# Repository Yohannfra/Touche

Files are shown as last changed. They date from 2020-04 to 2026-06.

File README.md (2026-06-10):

# Touché



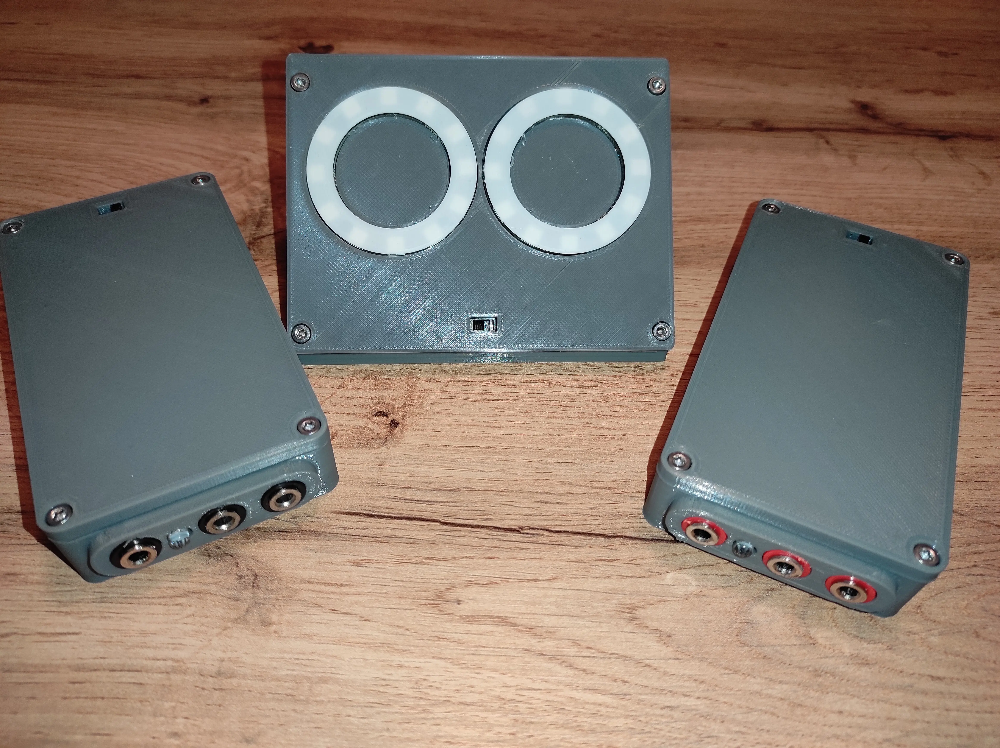
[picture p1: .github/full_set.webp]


## Overview

Touché is a wireless scoring system for fencing based on **Arduino** and **nrf24l01**.

The goal is to make an **affordable**, **open source** and **open hardware** system.

⚠️  The capacitive touch feature (used to detect whether a hit landed on a conductive surface like the guard or a metallic piste, replacing the ground wires of a traditional setup) is currently very buggy and not usable, which makes the system hard to use with **foil**.

⚠️  Foil and  sabre support is in the roadmap but in a latter version that will certainly be on a different mcu (ESP32 or STM32).

#### The system is divided into 3 parts: one base station and two fencer boxes.

*During the early days of this project I called the base station the **server**
and the fencer boxes the **clients**, I will use this naming in this document
and across the project.*

## Getting started

To make a system you'll have to go through these steps:
1. Order the PCB and all the components
2. 3D print the boxes
3. Program the Arduino
4. Solder the PCB and assemble everything
5. Enjoy!

I wrote a step-by-step tutorial that you can find in [Assembly_Guide](./Assembly_Guide).

If you have a question about anything (please read the tutorial first) you can open a Github issue and I will try my best to answer you.

## About the directory structure

This repository contains all the **sources**, **3D files**, and **PCB files** needed to make this system.

```
.
├── Archive           # some old versions of the project
├── Documents         # pcb sources, and STL files
├── Code              # source code
├── Assembly_Guide/   # step by step tutorial to DIY
```
Each directory has its own README.md to explain this with more details.

## Roadmap

See Github issues.

## Contribute

If you have any improvement idea, find a bug or encounter a problem you can open a Github issue.

## License

All the code, CAD files, PCB files, and everything within this repository is licensed under the terms of the [GNU General Public License V3.0](./LICENSE).

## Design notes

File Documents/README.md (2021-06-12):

# Documents

This directory contains all CAD files, 3D files (STL), and PCB files.

````
.
├── CAD       # CAD and STL files for 3D printing
└── PCB       # PCB sources and gerber files
```

Each directory has its own README.md to explain this with more details.

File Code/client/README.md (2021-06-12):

# Client source code

### Build

You must have the pio command available.

```bash
make           # debug version
make_release   # release version
```

### Flash

```bash
make flash           # debug version
make flash_release   # release version
```

### Change the default player

If it's the first time you program and Arduino with this code you must set which 'Player' it will be, it can be **PLAYER_1** or **PLAYER_2**
Once it's done once for an Arduino you should not need to change that anymore.

Change it in **./include/config.h** line 28

```cpp
#define PLAYER_ROLE PLAYER_1  // change value to PLAYER_1 or PLAYER_2
```

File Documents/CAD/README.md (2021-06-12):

# CAD

This directory contains the 3D STL files for the 2 boxes.

## Print settings

I printed all parts with **0.2 layer height** and **20% infill**.

I printed them all on my ender 3 pro so I don't think any of them can be considered as a difficult print.

You'll need supports for the **client's base** and the **server's base**.

You can print in any color but should print the server light diffuser in white for better results.

You can print in any material.

## Print time

This is just to give you an idea of the print time I had on my **ender 3 pro** at **50 mm/s** (and most of Cura's defaults settings) for PLA

| Part | Time  |
| --- | ----- |
| Client base | ~6h |
| Client lid  | ~4h |
| Server base | ~7h |
| Server lid  | ~4h |
| Light diffuser| 5 min |

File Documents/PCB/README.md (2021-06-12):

# PCB

This directory contains the PCB files and the Gerbers for the 2 boxes.

## Order the PCBs

Check the chapter about the PCB ordering in the [Assembly guide](../../Assembly_Guide/README.md)

## Quick note

I designed these PCBs with Eagle.

The Arduino nano and NRF24L01 parts come from here: https://www.diymodules.org/

I learned PCB with this project so they may not be perfect.

Please open an issue if you spot any design error.

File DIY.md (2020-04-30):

# A tutorial to help you create your wireless fencing system

## Components and supplies

- [3 : esp32 devboards](https://www.amazon.fr/AZDelivery-NodeMCU-d%C3%A9veloppement-d%C3%A9nergie-successeur/dp/B074RGW2VQ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)
- [3 : Neopixel ring](https://www.amazon.fr/dp/B07TZK9DNT/ref=twister_B0822WQBQX?_encoding=UTF8&psc=1)
- [1 : 12V buzzer](https://www.amazon.fr/LZQ-3022-Discontinu-alarme-Avertisseur-Sonore/dp/B010V4UVHG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)
- [6 : banana plugs](https://www.amazon.co.uk/KEESIN-Binding-Amplifier-Terminal-Connector-Type-D/dp/B077T2FC7K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)
- [3 : micro USB Tp4056 charger circuits](https://www.amazon.fr/Tp4056-Chargeur-Batterie-Lithium-Charger/dp/B07NVBLMVQ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)
- [3 : 3.7V batteries](https://www.amazon.fr/dp/B07KKB874V?ref=ppx_pop_mob_ap_share)
- [3 : power switches](https://www.amazon.fr/TOOGOO-broches-Positions-commutateur-glissiere/dp/B00X3KCA0M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)

#### Total cost : ~ 100€

## Building tools

- soldering iron
- 3d printer (i used an Ender 3, so event a cheap one should work)
- screwdriver
- a few screw
- some electric wire
- a hot glue pistol

## 3d printing

You can find all the files to print [here](thingverselink).

You need to print
- 2 : client_base.stl
- 2 : client_cover.stl
- 1 : server_base.stl
- 1 : server_cover.stl

The two bases need printing support.\
On my ender 3 without the adhesion it fails so i'd reccomend you to print all parts with adhesion.

## Flashing the boards

**An unix based system is needed for this part (Linux/Mac)**

- Install the [Arduino IDE](https://www.arduino.cc/en/Main/Software)
- Install [PlatformIO](https://platformio.org/)
- Clone and go to the repository
    ```
    $ git clone https://github.com/Yohannfra/WSFF && cd WSFF
    ```
- Sort yours esp32, 2 will be the clients and one will be the server
- Change directory
    ```
    $ cd tools/get_esp32_mac_address
    ```
- For each esp32 :
    - Plug the board to the computer and type
        ```
        make && make flash
        ```
    - Open screen to view the value of the mac address
        ```
        screen /dev/ttyUSB0 115200
        ```
    - Edit the file **constants.cpp** and replace the mac addresses with yours
        ```
            $ nano ../../shared/constants.cpp
        ```
    - Unplug the board

- Now go to the client directory
    ```
    $ cd ../../client/
    ```
- For your two client boards
    - Plug the board to the computer and type
        ```
        $ make && make flash
        ```
    - Unplug the board
- Now the server board
    ```
        cd ../server/
    ```
    - Plug the board to the computer and type
        ```
        $ make && make flash
        ```
    - Unplug the board

- Done !

## Soldering and assembling

**You need all the 3d printed parts now**

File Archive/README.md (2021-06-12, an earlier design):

# Archive

This directory contains the code of some early prototypes I did. I don't know if they work or even compile.
I keep this directory just to keep trace of these old prototypes.

**esp32_arduino_v1** and **esp32_espidf_v2** were made to run on Espressif ESP32 chip and used ESP-NOW.
Around the end of the v2, I realized that the ESP32 consumed way too much power and started over with Arduino nano.

The v1 coded with the Arduino framework and the v2 with the ESP-IDF framework.

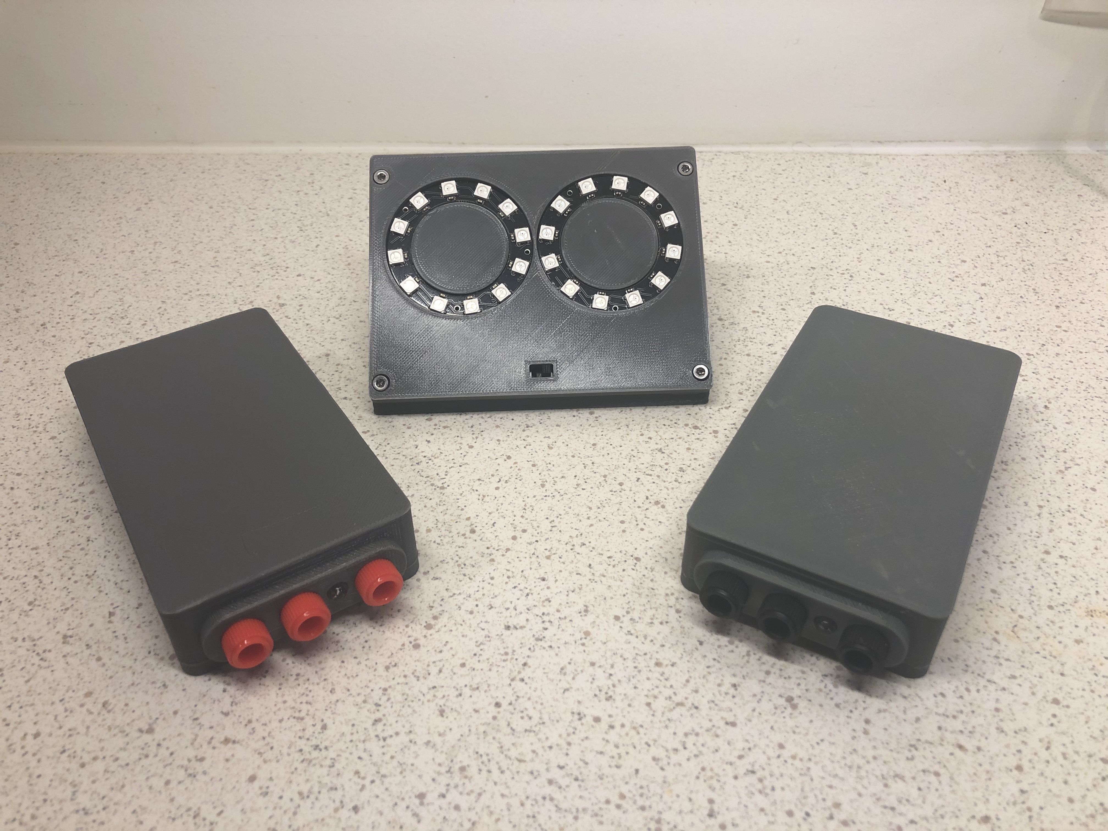
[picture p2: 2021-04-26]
.github/full_set.jpg

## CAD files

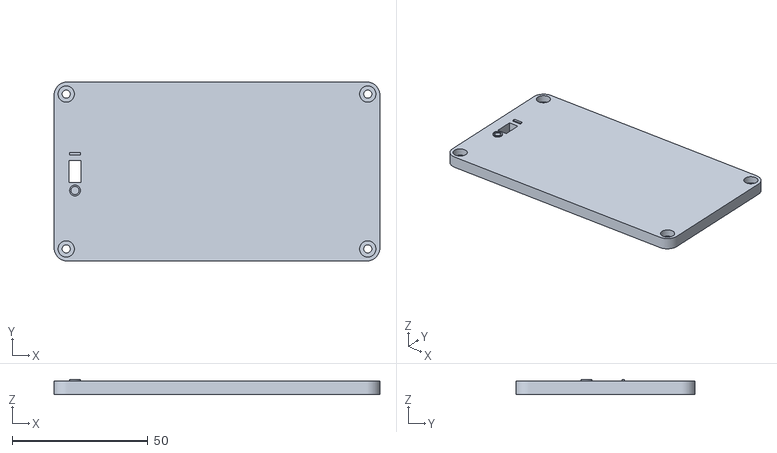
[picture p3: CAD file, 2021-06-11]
Documents/CAD/client/lid_client.stl
120.0 x 66.0 x 5.50

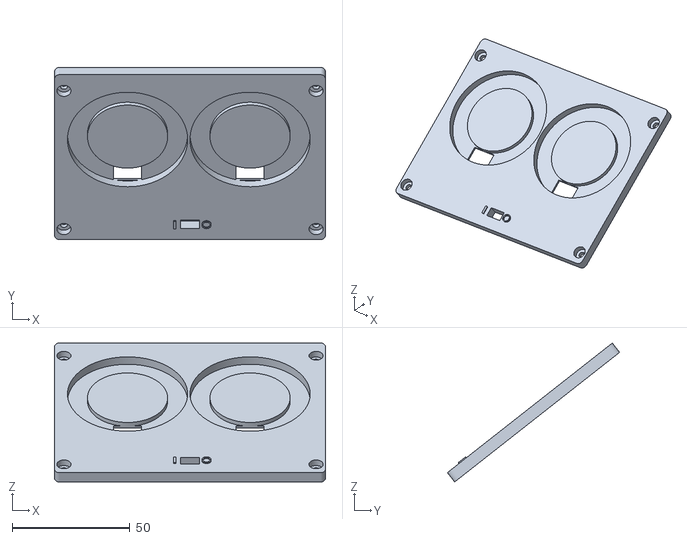
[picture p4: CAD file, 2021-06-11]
Documents/CAD/server/lid_server.stl
115.0 x 73.1 x 58.9

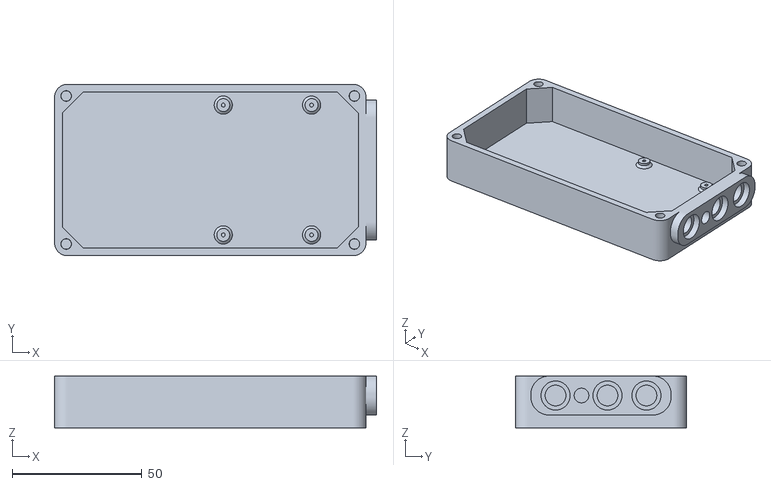
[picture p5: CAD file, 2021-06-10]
Documents/CAD/client/base_client.stl
124.0 x 66.0 x 20.0

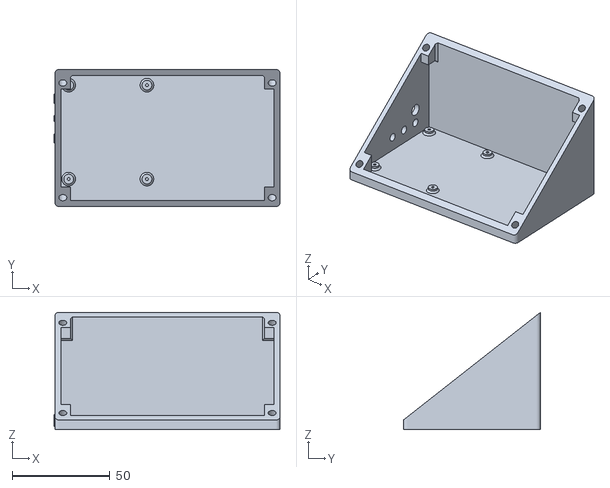
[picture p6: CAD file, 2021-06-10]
Documents/CAD/server/base_server.stl
115.5 x 70.0 x 60.0

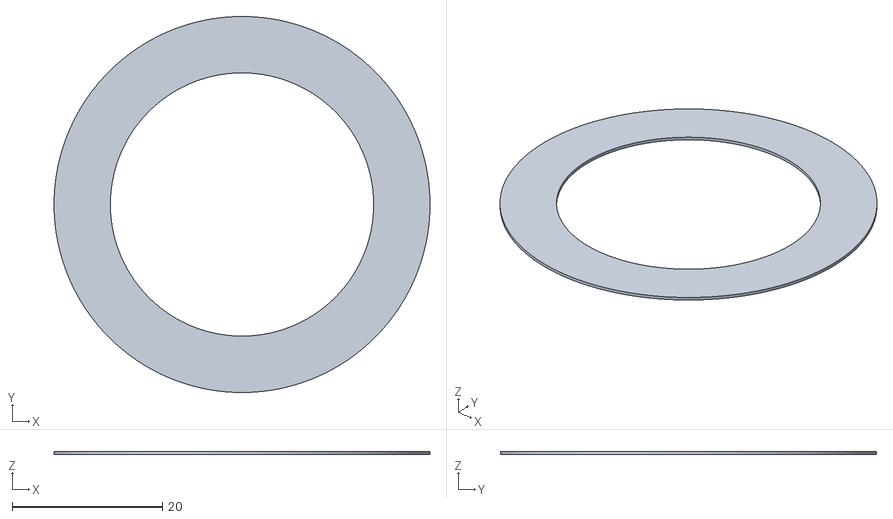
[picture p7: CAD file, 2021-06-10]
Documents/CAD/server/light_diffuser.stl
50.0 x 50.0 x 0.4

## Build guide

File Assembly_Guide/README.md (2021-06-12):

# Assembly guide

In this document, I will go through all the steps and explain everything needed to make a complete Touché system.

The total cost of the system sits somewhere around **50 euros** but since most parts are sold in batch you might pay a little more and end up with unused parts at the end of the assembly.

#### Table of Contents

1. [Parts, material and required tools](#p1)
2. [PCB](#p2)
3. [3D printing](#p3)
4. [Assembly](#p4)
5. [Testing / Usage](#p5)

<a name="p1"/>

### 1. Parts, material, and required tools

##### Here are all the parts required.

| Name | Quantity | URL  |
| --- | --- | ---- |
| Arduino nano | 3 | [Aliexpress](https://fr.aliexpress.com/item/32647196840.html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,searchweb201602_,searchweb201603_) [Arduino store](https://store.arduino.cc/arduino-nano) [Amazon](https://www.amazon.fr/Elegoo-Pi%C3%A8ces-ATmega328P-Contr%C3%B4leur-Arduino/dp/B0722YYBSS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) |
| NRF24L01 | 3 | [Aliexpress](https://fr.aliexpress.com/item/32517849393.html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,searchweb201602_,searchweb201603_) [Amazon](https://www.amazon.fr/AZDelivery-NRF24L01-Antenne-emetteur-recepteur-R%C3%A9cepteur/dp/B06XJN417D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) |
| AA battery case | 3 | [Aliexpress](https://fr.aliexpress.com/item/1005001707889794.html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,searchweb201602_,searchweb201603_) [Amazon](https://www.amazon.fr/HUAYAO-Batterie-Plastique-Stockage-Transparent/dp/B08VDHCD66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) |
| 10uF 16v electrolytic capacitor | 3 | [Aliexpress](https://fr.aliexpress.com/item/32812085542.html?spm=a2g0o.cart.0.0.3a7f3c00e96C79&mp=1) |
| RGB led (common cathode) | 2 | [Aliexpress](https://fr.aliexpress.com/item/32757977782.html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,searchweb201602_,searchweb201603_) |
| Neopixel ring (12 pixels, 50 mm diameter) | 2 | [Aliexpress](https://fr.aliexpress.com/item/32835427711.html?spm=a2g0s.9042311.0.0.27426c37UHtlV5) |
| Banana socket | 6 | [Aliexpress](https://fr.aliexpress.com/item/32871913429.html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,searchweb201602_,searchweb201603_) |
| Slide switch | 3 | [Aliexpress](https://fr.aliexpress.com/item/32807468914.html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,searchweb201602_,searchweb201603_) [Amazon](https://www.amazon.fr/Lezed-Interrupteur-Horizontal-commutateur-horizontal/dp/B07LBPDB6S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) |
| Threaded inserts (M3 x 5,7mm) | 12 | [Aliexpress](https://fr.aliexpress.com/item/4001258499799.html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,searchweb201602_,searchweb201603_) |
| 1MΩ resistor | 6 | Full ressistor Kit [Amazon](https://www.amazon.fr/ELEGOO-R%C3%A9sistance-Electroniques-Exp%C3%A9rimentalur-Exp%C3%A9rimental/dp/B071LHFQKD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) [Aliexpress](https://fr.aliexpress.com/item/1005001968824337.html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,searchweb201602_,searchweb201603_) |
| 10 KΩ resistor | 2 | Same ressistor Kit |
| 0 Ω resistor | 2 | Same ressistor Kit |
| 220 Ω resistor | 6 | Same ressistor Kit |
| Buzzer SFM-27 | 1 | [Aliexpress](https://fr.aliexpress.com/item/1005002095783515.html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,searchweb201602_,searchweb201603_) [Amazon](https://www.amazon.fr/YANSHON-Buzzer-dAlarme-Avertisseur-%C3%A9lectronique/dp/B07RY42FQ5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) |
| AA battery | 9 | [Amazon](https://www.amazon.fr/Duracell-Plus-Power-Piles-Alcalines/dp/B005EJFLJC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) or any local store |
| Bolt (M3 x 10) | 12 | [Aliexpress](https://fr.aliexpress.com/item/33012853233.html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,searchweb201602_,searchweb201603_) [Amazon](https://www.amazon.fr/100pcs-Boulon-Hexagonale-Cylindrique-inoxydable/dp/B073ZY19VS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) |
| Mini screws (M1.75 x 5) | 12 | [Aliexpress](https://fr.aliexpress.com/item/4000930559532.html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,searchweb201602_,searchweb201603_) [Amazon](https://www.amazon.fr/1000pcs-minuscules-crois%C3%A9e-dassortiment-autotaraudeurs/dp/B07WXHH6ZL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) |
| 5kΩ potentiometer | 1 | [Aliexpress](https://www.aliexpress.com/item/1005002056193990.html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,searchweb201602_,searchweb201603_) |
| Right angle push button switch (6 x 6 x 9 mm) | 3 | [Aliexpress](https://www.aliexpress.com/item/32901481925.html?spm=a2g0s.9042311.0.0.17af6c37yXC24E) |

##### Tools / consumables you'll need

- 3D printer (I printed all the parts on my Ender 3 so I think any decent printer could get the job done)
- Soldering iron and solder wire
- Hot glue gun and glue
- Screwdrivers
- Wire cutting pliers
- A few wires (I have [those](https://www.amazon.com/TUOFENG-Wire-Solid-different-colored-spools/dp/B07TX6BX47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))

<a name="p2"/>

### 2. PCB

Ordering the PCBs is quite simple and cheap. I will show how to do it with [JLCPCB](https://jlcpcb.com/) but it should be similar on [PCBWay](https://www.pcbway.com/) or any similar website.

1. Go to https://jlcpcb.com/

2. Leave all the defaults settings and click on 'Quote now'

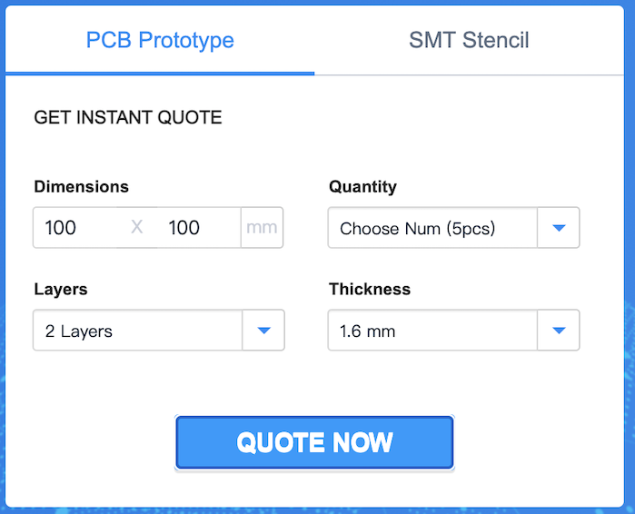
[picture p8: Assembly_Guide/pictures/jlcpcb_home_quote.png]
jlcpcb_home_quote


3. Import the client's gerber file (it the .zip in [this](https://github.com/Yohannfra/Touche/tree/master/Documents/PCB/client) directory)

jlcpcb_import_gerber

4. Save to cart and **repeat this process for the server's gerber file** ([here](https://github.com/Yohannfra/Touche/tree/master/Documents/PCB/server))

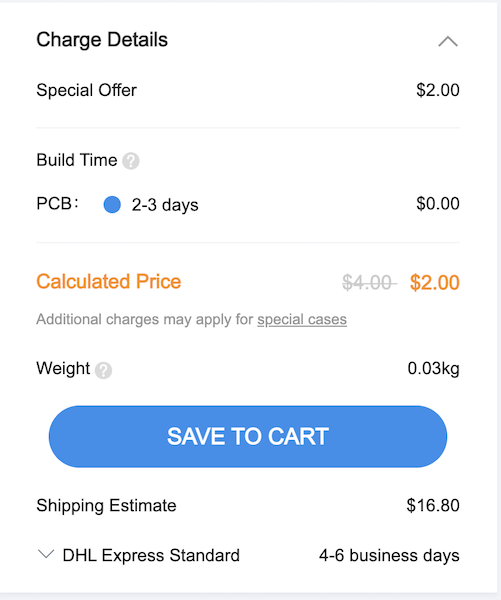
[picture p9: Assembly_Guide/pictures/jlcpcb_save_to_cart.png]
jlcpcb_save_to_cart


5. Pay and order.

<a name="p3"/>

### 3. 3D printing

8 printed parts are needed for the assembly :

| Name | Link | Quantity | Time needed | Supports |
| --- | --- | --- | --- | --- |
| Client's base | [url](https://github.com/Yohannfra/Touche/tree/master/Documents/CAD/client/base_client.stl) | 2 | ~4h | Yes |
| Client's lid | [url](https://github.com/Yohannfra/Touche/tree/master/Documents/CAD/client/lid_client.stl) | 2 | ~4h | No |
| Server's base | [url](https://github.com/Yohannfra/Touche/tree/master/Documents/CAD/server/base_server.stl) | 1 | ~6h | Yes |
| Server's lid | [url](https://github.com/Yohannfra/Touche/tree/master/Documents/CAD/server/lid_server.stl) | 1 | ~4h | No |
| Light diffuser | [url](https://github.com/Yohannfra/Touche/tree/master/Documents/CAD/server/light_diffuser.stl) | 2 | ~10 min | No |

I recommend printing all of them with **20% infill** and **0.2mm layer height** and face up.

<a name="p4"/>

### 4. Assembly

Before starting the assembly make sure you have everything, you should have all the parts shown in this picture:

all_parts

The assembly process is divided in 5 steps :
1. [client's pcb](./Step1.md)
2. [server's pcb](./Step2.md)
3. [programming](./Step3.md)
4. [client's assembly](./Step4.md)
5. [server's assembly](./Step5.md)

<a name="p5"/>

### 5. Testing / Usage

##### Turn on of the client, if the led is :
- Red -> Epee mode
- BLUE -> Foil mode
- GREEN -> Sabre mode (Not implemented yet)
- Something else / nothing -> Something is wrong, check the assembly guide again.

##### Same for the second client.

##### Now turn on the server, the led rings should blink in orange, if no check the assembly guide again.

### For epee

Plug your epee in, if you press the button the server will signal it.

By default if you touch the opponent guard it won't detect it, you must calibrate it.

To calibrate the client you need to maintain the button of your epee on his guard until the server LED blinks in led (~3 seconds). If it blinks in red, an error occurred and you must try again.\
This needs to be done each time something changes (new opponent, new weapon, new shoes, different piste ...).

Both opponents need to do this once and the system will be good to go.

One player will be signaled in green and the other one in red.

### For foil

Plug your foil in, if you press the button the server will signal it as an invalid hit.

By default all hits will be invalid, you must calibrate it.

To calibrate the client you need to maintain the button of your foil on electric jacket until the server LED blinks in led (~3 seconds). If it blinks in red, an error occurred and you must try again.\
This needs to be done each time something changes (new opponent, new weapon, new shoes, different piste ...).

Both opponents need to do this once and the system will be good to go.

One player will be signaled in green and the other one in red.

### About the buttons on the side of the server

There are 3 buttons and a potentiometer on the side of the server box.

The potentiometer controls the volume of the buzzer.

Starting from the left:
- First buttons are here to switch sides, eg. Player 1 hits are signaled on the left but he is on the right side of the server, press this button and he will be signaled on the right.
- Second button toggles piste mode, it will detect the piste and won't signal if a hit occurs on it (still not tested because I don't have an electric piste at home but it should work)
- Third button changes weapon, press it and then hit with each player weapon to 'transfer the information' so the next hit will be in the new weapon mode.

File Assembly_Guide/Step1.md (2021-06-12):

# Step 1 : Client's PCB

This first step is for soldering everything onto the client's pcb. Since there are 2 clients you'll need to **do this step twice**.

1. Take the client's pcb



2. Take the Arduino Nano (and solder the leads if needed)

before the leads

after the leads

3. Solder the Arduino Nano on the pcb

arduino soldered

4. Take the NRF24L01 and solder it on the pcb

nrf soldered

5. Take the 10uF capacitor and solder it (be careful, it's a polarized capacitor and therefore the positive side must match the little + on the pcb)

take the cap

solder the cap

6. take the 3 220 ohms resistors and solder them

3 220 ohms

3 220 soldered

7. Take the 10k ohms resistor and solder it

10k resistor

10k soldered

8. Take the 2 1M ohms resistors and solder them

2 1M resistors

2 1M soldered

9. Take the RGB led and solder it. Be careful, of the side and place it like on the picture before soldering. Once soldered, bend the leads like on the pictures.

rgb led

rgb led soldered

10. Flip the pcb and cut all the leads

    cut the leads

leads cut

11. Take one of the lead and solder it across the empty resistor slot.

take a lead

solder the lead

And ... Done ! Now repeat all these steps a second time for the second pcb. At the end you should have two pcbs like that:

two clients's pcbs

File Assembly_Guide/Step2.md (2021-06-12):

# Step 2 : Server's PCB

This second step is for soldering everything onto the server's pcb.

1. Take the server's pcb

server pcb

2. Take the 3 buttons and solder them

3 buttons

buttons soldered

3. Take the potentiometer and solder it

potentiometer

potentiometer soldered

4. Take the NRF24L01 and solder it

take nrf24

solder nrf24

5. Take the Arduino Nano (solder the leads if needed) and solder it on the pcb

before the leads

after the leads

arduino nano and pcb

arduino nano soldered

5. Take the 10uF capacitor and solder it (be careful, it's a polarized capacitor and therefore the positive side must match the little + on the pcb)

take cap

solder cap

And you're done with the pcbs ! Now you should have all three pcbs :

all pcbs

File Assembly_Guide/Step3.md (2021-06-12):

# Step 3 : Programming

In this step I'll show how to program everything.

In this step I'll do everything with the command line (I'm on Mac) and those commands also work on linux. If you're on Windows you could use [WSL](https://docs.microsoft.com/fr-fr/windows/wsl/install-win10) or try to do everything with vscode.

Clone the git repository

```
$ git clone https://github.com/Yohannfra/Touche
```

Install platformio core : https://docs.platformio.org/en/latest//core/installation.html

Once it's done you should have the command pio

```
$ pio --version
PlatformIO Core, version 5.1.1
```

### Select the default weapon

in **Code/shared/touche.h** line number **78**

by default it's
```c
#define DEFAULT_WEAPON_MODE EPEE
```

For now only **EPEE** and **FOIL** are available.

### Server

Go to the server's directory

```
$ cd Code/server/
```

Build the code

```
$ make release
```

Plug the server's pcb

plug the server's pcb

and run

```
$ make flash_release
```

You can now unplug the server's pcb.

### Client

Now go to the client's directory

```
$ cd ../client
```

Build the code

```
$ make release
```

Plug the first pcb (**only the first**)

flash client

and run

```
$ make flash_release
```

you can unplug the pcb. Normally when the **make flash_release** ended the led blinked in red.

Now you'll have to edit a file, open **include/config.h"** in the client's directory and change this line (line 28)

```c
#define PLAYER_ROLE PLAYER_1  // change value to PLAYER_1 or PLAYER_2
```

to

```c
#define PLAYER_ROLE PLAYER_2  // change value to PLAYER_1 or PLAYER_2
```

Now save the file and close it.

Now build the code again

```
$ make release
```

Plug the second client's pcb and run

```
$ make flash_release
```

And now you should be done with the programming part. You can skip the next part if you want to make only one system.

## If you want to make multiple systems

Between each system you should change the nrf24l01 pipes addresses, it's in the file **Touche/Code/shared/radioPipes.h"**

The default pipe address is

```cpp
static const uint64_t PIPES_ADDRESSES[2] = {
    0xB3B4B5B601LL,  // PLAYER 1
    0xB3B4B5B602LL   // PLAYER 2
};
```

You can change that to anything as long as :

- The length is the same
- The two addresses are different
- You keep the **0x** at the beginning and the **LL** at the end

A few valid examples:

```cpp
static const uint64_t PIPES_ADDRESSES[2] = {
    0xB5C4B5B601LL,  // PLAYER 1
    0xB5C4B5B602LL   // PLAYER 2
};

static const uint64_t PIPES_ADDRESSES[2] = {
    0xB1B4B5B601LL,  // PLAYER 1
    0xB1B4B5B602LL   // PLAYER 2
};

static const uint64_t PIPES_ADDRESSES[2] = {
    0xA9B4B5B601LL,  // PLAYER 1
    0xA9B4B5B602LL   // PLAYER 2
};

// ...
```

Refer to this thread if you want to know more about it: https://arduino.stackexchange.com/questions/2946/nrf24l01-pipe-question

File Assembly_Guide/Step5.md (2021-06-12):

# Step 5 : Server's assembly

This step is for assembling the server's pcb to the printed parts and finishing the server's box.

1. Take the server's base and 4 threaded inserts, place them in the holes and push them inside with a soldering iron  (watch [this video](https://www.youtube.com/watch?v=KqSmCHr4fdA) if you need help)





2. Take the server's lid, a slide switch, 2 screws and screw the switch.





3. Now take the 2 led rings and glue them in the slots with the glue gun, make sure the pins are accessible in the hole on the back of the lid.









4. Take the light diffusers and glue them on top of the rings





5. Take the server's pcb and the buzzer and solder the buzzer





6. Take 5 wires, 1x9cm and 4x5cm



take the server's lid



And solder them like this, the **DO** of the first ring must be connected to the **DI** of the second one



7. Take 3x8cm wires and 2 heat shrink tubes



Place the heat shrink tubes like this



Solder the matching wires



Solder the new wires at the connection and place the heat shrink tubes around the exposed part and heat them



8. Take the pcb and the lid



Solder the wires to the pcb



9. Take a 9cm wire and solder it to the middle pin of the slide switch and to the **VCC** of the pcb





10. Take the base, the lid and 2 screws and screw the pcb





11. Take the AA battery holder and cut it's wires like this



Take the glue gun and glue the AA battery holder and the buzzer









12. Solder the red wire of the AA battery holder to the left side pin of the slide switch



13. Take the 3 AA batteries and place them in the holder





14. Take the M3 screws and close the lid





And you're done ! Now you should have all the three parts



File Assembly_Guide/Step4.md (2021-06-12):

# Step 4 : Client's assembly

This step is for assembling the client's pcb to the printed parts and finishing the clients boxes.

1. Take the client's base and 4 threaded inserts, place them in the holes and push them inside with a soldering iron (watch [this video](https://www.youtube.com/watch?v=KqSmCHr4fdA) if you need help) 

client and inserts

inserts placed

inserts in

2. Take the client's lid, the slide switch and 2 screws and screw the button

lid and switch

slide switch placed

3. Take the client's base and 3 banana sockets (like shown on the picture). Screw the sockets.

all banana sockets

banana sockets placed

4. Take the **client's base**, **three 3cm  long wires** and the client's pcb 





Solder the wires on the pcb.



Now take 3 screws and screw the pcb.





Solder the wires onto the banana sockets



5. Take the AA battery holder



Cut the wires, the black one around 5cm and the red one around 9cm



6. Take the client's base, the AA battery holder and a hot glue gun, and glue the battery holder like shown in the picture







7. Solder the black wire to the GND pin on the pcb



Slide the wire on between the AA holder and the side of the case



7. Take a 12cm wire, the client's lid and solder the wire to the right pin of the switch







8. Now take the base and the lid



Solder the red wire to the middle pin of the switch and the white wire to the VCC pin of the pcb



9. Take 3 AA batteries and place them inside the holder





10. Close the lid and screw it with 4 M3 screws







And you're done ! Now do it again for the second client.

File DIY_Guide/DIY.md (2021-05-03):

# DIY guide

In this document I will go trough all the steps and explain everything needed to make a complete Touché system.

The total cost of the system sits somewhere around **50 euros** but since most parts are sold in batch you might pay a little more and end up with unused parts at the end of the assembly.

#### Table of Contents

1. [Parts, material and required tools](#p1)
2. [PCB](#p2)
3. [3D printing](#p3)
4. [Programming](#p4)
5. [Assembly](#p5)
6. [Testing](#p6)

<a name="p1"/>

### 1. Parts, material and required tools

##### Here are all the parts required.

| Name | Quantity | URL  |
| --- | --- | ---- |
| Arduino nano | 3 | [Aliexpress](https://fr.aliexpress.com/item/32647196840.html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,searchweb201602_,searchweb201603_) [Arduino store](https://store.arduino.cc/arduino-nano) [Amazon](https://www.amazon.fr/Elegoo-Pi%C3%A8ces-ATmega328P-Contr%C3%B4leur-Arduino/dp/B0722YYBSS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) |
| NRF24L01 | 3 | [Aliexpress](https://fr.aliexpress.com/item/32517849393.html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,searchweb201602_,searchweb201603_) [Amazon](https://www.amazon.fr/AZDelivery-NRF24L01-Antenne-emetteur-recepteur-R%C3%A9cepteur/dp/B06XJN417D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) |
| AA battery case | 3 | [Aliexpress](https://fr.aliexpress.com/item/1005001707889794.html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,searchweb201602_,searchweb201603_) [Amazon](https://www.amazon.fr/HUAYAO-Batterie-Plastique-Stockage-Transparent/dp/B08VDHCD66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) |
| 10uF 16v electrolytic capacitor | 3 | [Aliexpress](https://fr.aliexpress.com/item/32812085542.html?spm=a2g0o.cart.0.0.3a7f3c00e96C79&mp=1) |
| RGB led (common cathode) | 2 | [Aliexpress](https://fr.aliexpress.com/item/32757977782.html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,searchweb201602_,searchweb201603_) |
| Neopixel ring (12 pixels, 50 mm diameter) | 2 | [Aliexpress](https://fr.aliexpress.com/item/32835427711.html?spm=a2g0s.9042311.0.0.27426c37UHtlV5) |
| Banana socket | 6 | [Aliexpress](https://fr.aliexpress.com/item/32871913429.html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,searchweb201602_,searchweb201603_) |
| Slide switch | 3 | [Aliexpress](https://fr.aliexpress.com/item/32807468914.html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,searchweb201602_,searchweb201603_) [Amazon](https://www.amazon.fr/Lezed-Interrupteur-Horizontal-commutateur-horizontal/dp/B07LBPDB6S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) |
| Threaded inserts (M3 x 5,7mm) | 12 | [Aliexpress](https://fr.aliexpress.com/item/4001258499799.html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,searchweb201602_,searchweb201603_) |
| 1MΩ resistor | 6 | Full ressistor Kit [Amazon](https://www.amazon.fr/ELEGOO-R%C3%A9sistance-Electroniques-Exp%C3%A9rimentalur-Exp%C3%A9rimental/dp/B071LHFQKD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) [Aliexpress](https://fr.aliexpress.com/item/1005001968824337.html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,searchweb201602_,searchweb201603_) |
| 10 KΩ resistor | 2 | Same ressistor Kit |
| 0 Ω resistor | 2 | Same ressistor Kit |
| 220 Ω resistor | 6 | Same ressistor Kit |
| Buzzer SFM-27 | 1 | [Aliexpress](https://fr.aliexpress.com/item/1005002095783515.html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,searchweb201602_,searchweb201603_) [Amazon](https://www.amazon.fr/YANSHON-Buzzer-dAlarme-Avertisseur-%C3%A9lectronique/dp/B07RY42FQ5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) |
| AA battery | 9 | [Amazon](https://www.amazon.fr/Duracell-Plus-Power-Piles-Alcalines/dp/B005EJFLJC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) or any local store |
| Bolt (M3 x 10) | 12 | [Aliexpress](https://fr.aliexpress.com/item/33012853233.html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,searchweb201602_,searchweb201603_) [Amazon](https://www.amazon.fr/100pcs-Boulon-Hexagonale-Cylindrique-inoxydable/dp/B073ZY19VS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) |
| Mini screws (M1.75 x 5) | 16 | [Aliexpress](https://fr.aliexpress.com/item/4000930559532.html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,searchweb201602_,searchweb201603_) [Amazon](https://www.amazon.fr/1000pcs-minuscules-crois%C3%A9e-dassortiment-autotaraudeurs/dp/B07WXHH6ZL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) |

##### Tools you'll need

- 3D printer (I printed all the parts on my 150$ ender 3 so IMO any decent printer could do the job)

- Soldering iron

- Hot glue gun

- Screwdriver 

- Wire cutting pliers

##### Additional material

- Hot glue
- Solder wire
- A few wires (I have [those](amazon.com/TUOFENG-Wire-Solid-different-colored-spools/dp/B07TX6BX47/ref=sr_1_5?dchild=1&keywords=wires&qid=1620082408&sr=8-5))

<a name="p2"/>

### 2. PCB

<a name="p3"/>

### 3. 3D printing

<a name="p4"/>

### 4. Programming

<a name="p5"/>

### 5. Assembly

<a name="p6"/>

### 6. Testing

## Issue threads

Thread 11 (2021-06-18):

Could Touche be adapted for Boffer Combat?

DrAlta, 2021-06-18:
Hello. I was to use an automated scoring system for my Boffer Combat.

The main things I can think of is that Boffer Combat has many opponents at one and multi hit locations.

Would I just have change the software to track more that 2 combatants then to change the hardware to add multiple lamè connectors?

Edit: correct epee to lamè

Yohannfra, 2021-06-18:
Hello.
I don't know anything about Boffer Combat, is there already an electric system (wireless or no) that works ?

A fencing epee/foil has a button and an electric wire within the blade conducting the button state, I don't think there is something similar for Boffer Combat weapons.

DrAlta, 2021-06-18:
I just learned the the Epee is a type of weapon the armor is called lamè.

I failed the math part of first semester of Electronic Repair Technician program I was in, now I do software.
I don't know of any automatic scoring systems than Fencing's and Unified Weapons Master which w never released and has been quite since 2017.

How do you detect if a hit is valid?

I guess it would be more like sabre which you don't support yet....

Yohannfra, 2021-06-19:
I detect if a hit occurred using the button at the tip of the epee/foil.

Yes it's more like sabre and seems to be more complicated since weapons are in foam.

I think this is out the scope of Touché for now and prefer to stay focused on traditional fencing with foil, epee and sabre.

You can still fork and try to find a way to make it work but I don't think it will be trivial.

Closed 2021-07-02.

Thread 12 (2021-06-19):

Interested in this project

young-oct, 2021-06-19:
Hi there,

Very cool project and I'm interested in knowing more. I'm wondering if you have some research material to tackle this project. Feel free to contact me by dropping me an email young.wang93@gmail.com

Yohannfra, 2021-06-19:
Hello,
Glad to hear you're interested in this project !

I didn't write any documentation while researching but a complete diagram + some doc about how it works is planned. What else would you need to tackle it ?

young-oct, 2021-06-29:
@Yohannfra hello. Sorry about the late response. I'm a fencer myself and have been always interested in doing a project like this. And I think it would be fun to learn some PCB design and programming while doing it. It's great that complete diagram + some doc is planned/

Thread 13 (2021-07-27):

Wiring question...

bhfoilist, 2021-07-27:
I've built the boxes and checked that they are working by enabling debug mode.  I'm able to see messages between the client and server, and it seems like epee touches work.  Unfortunately, they also trigger on the bell guard.  Is the capacitive sensor supposed to detect the bell guard and disable the signal?

Also, I'm not sure foil is working correctly, and it seems like the pins might be mixed up.  Normally, the middle pin on the foil body cord carries the voltage up the wire in the weapon; however, the voltage seems to be on the alligator clip instead.  Can you explain how the pins are intended to work with this system?  I only get foil touches if I connect the weapon (not the tip) to the alligator clip--not if I press the tip.

Thanks!

Yohannfra, 2021-07-29:
Hello, yes the foil mode is broken and not usable yet. I update the README.

The problem you have seems not related to the capacitive sensor, can you provide more infos about your bug ? (any logs ?)

paxon1, 2022-09-23:
Hello,
  I am troubleshoot a first time build, which I assume is a soldering problem. How do I enable debug more to verify wireless connectivity between client/server.

Yohannfra, 2022-09-26:
Hi @paxon1, as it is written in the documentation to enable the debug mode and view the mode just build with ```make``` then flash with ```make flash```

link: https://github.com/Yohannfra/Touche/tree/master/Code/client

luczynski, 2023-08-03:
hi- after chenging  on player_2  and uploading in VCS -VISUAL CODE  - EWRYSING LITING  ONLY- RED COLER - one RED side  LITING ?  for two  player ? !   - HOW TEST ON GARDA  TOUCH -?
   wieslaw.luczynski@gmail.com      3.08.2023

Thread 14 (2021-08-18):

Timing question

ncaccamo, 2021-08-18:
Looking at touche.h, line 65 (as of Jun 13th commit), the double touch time is set to 300ms. Above in the comments, it is explained that there is ~260ms of processing time when both tips are pressed. For clarification, does this mean that the system cannot meet the rules timing requirements to distinguish between a single touch or double touch due to processing/communication delays?

I am also wondering what are good methods to measure these timings across the whole system given the various factors?

Yohannfra, 2021-08-30:
Yes, the rule says that a double hit must be made within 50ms but the minimum timing I got when pressing the two buttons at the exact same time was 260ms, so by setting 300ms I give a little more tolerance to this timing and it works better.
From what I tested the difference is almost not noticeable.

I don't have any 'good' method to test the timings, I just press the two buttons at the exact same time and read the millis() difference of the two when the server receive it

Riposte63, 2021-09-19:
Hi, There is also the question of how long the tip is depressed before a hit will register (I think 17ms for foil?) - is this in the code somewhere? I couldn't find it and would like to be able to adjust these timings.

Yohannfra, 2021-09-23:
You can look at client/lib/Weapon/src/Weapon.cpp and client/src/main.cpp

If the tip is pressed the hit will register instantly. where did you find 2ms ?
Actually It should wait a few ms but it was causing some latency so I removed it for now until I find a solution.

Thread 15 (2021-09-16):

Epee Mode

brunorosaa, 2021-09-16:
Hello, I recently did a project for my graduation in Eletrotecnic Engineering but my capacitive sensor sometimes works, sometimes not. I'm interested in your capacitive sensor, does it always work without any problem?
Thanks

Yohannfra, 2021-09-23:
Hello, no not at all for the moment. It kind of works for epee but is not reliable at all.
I'm now experimenting with other capacitive sensors solution (STM32L152 internal sensor) but it's not ready yet.

brunorosaa, 2021-09-23:
Hélio, thanks for the reply!
I try to use the internal capacitive sensor of an esp32 but it doesn’t have the necessary resolution. I’m just sharing my experience with that sensor’s. Keep the good work!
Best regards
Bruno Rosa

No dia 23/09/2021, às 08:57, Yohann ***@***.***> escreveu:

Hello, no not at all for the moment. It kind of works for epee but is not reliable at all.
I'm now experimenting with other capacitive sensors solution (STM32L152 internal sensor) but it's not ready yet.

—
You are receiving this because you authored the thread.
Reply to this email directly, view it on GitHub<https://github.com/Yohannfra/Touche/issues/15#issuecomment-925584617>, or unsubscribe<https://github.com/notifications/unsubscribe-auth/ANZBXAFH6QDKREZIQSBYC63UDLMV7ANCNFSM5EDUS7XQ>.
Triage notifications on the go with GitHub Mobile for iOS<https://apps.apple.com/app/apple-store/id1477376905?ct=notification-email&mt=8&pt=524675> or Android<https://play.google.com/store/apps/details?id=com.github.android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>.

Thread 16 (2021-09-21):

PWM detection instead of capacitance detection for future iterations

s0210310, 2021-09-21:
Hi,
Big fan of the project! I was also thinking of developing a system, but this is great. While researching the issue of detecting guard hits (talking epee specifically), the question has been posed multiple times, without a good answer besides capacitive sensing, which has its obvious drawbacks.

According to this thread, https://forum.arduino.cc/t/wireless-fencing-scoring-system-detecting-a-pwm-signal-without-common-ground/686963 the patent for true wireless systems uses PWM detection to discriminate against grounded hits. Now, the issue is that without a common ground, floating detector pins will give a lot of false negatives.

But, doing further investigation (reply nr 8 here https://www.avrfreaks.net/forum/communication-wout-common-ground) 100kHz and up signal could be detected reliably.
I believe with some care it's possible to use Arduino as a signal generator to drive 100kHz PWM signal to grounded surfaces and detect it with the depressed point. I'll try and experiment with this to confirm I can detect PWM without a common ground.

Your thoughts?

Yohannfra, 2021-09-23:
Hi,
As you can see at the end of the Arduino forum thread I talked with Luis320 in pm and from what I remember of our messages he could not get his pwm solution to work reliably enough for epee and for sabre it was too slow (from what he said).

If by experimenting you can find a way to make it work reliably it can be 100% better than capacitive sensing !

You said 'the patent for true wireless systems' does it means the pwm solution is patented and we can't use it at all ?

For you information last year I talked with @maxhaton and he tried to make it work using radio wave (see [here](https://www.reddit.com/r/Fencing/comments/g87ucg/successfully_detecting_a_fencing_hit_using_a/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)) so this could also be a solution.

Yohannfra, 2021-09-23:
Right now I'm sticking with capacitive sensing, I'm experimenting with the internal capacitive sensor of an STM32L152 but it would be interesting to compare all the solutions.

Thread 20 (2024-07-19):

Info about touch sensing and timing

wnew, 2024-07-19:
Hi @Yohannfra

Firstly what a great project. This  is something I have tried to implement myself over the years and I am excited to see that you have solved some of the problems I encountered. I would be keen to hear how you solve them.

On target sensing for foil? How did you manage this, was it with the capacitive sensor on the attacking fencer?

Then the timing between the 2 fencers, particularly lockout. How do you synchronise the 2 clients and then ensure that if an NRF packet is lost and needs to be re transmitted that it doesnt mess with the timing? Do you put a time stamp in the packet that is synced to the client clock?

Again, awesome project. I am keen to collaborate if you are interested to take this further.

Regards

W (Author of https://github.com/wnew/fencing_scoring_box)

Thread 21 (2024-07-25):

Collaboration

wnew, 2024-07-25:
Hi @Yohannfra,

I have been looking at this project and love what you have done. I am the author of the https://github.com/wnew/fencing_scoring_box.

I have been upgrading and creating a couple of PCB designs for my design and would like to collaborate. Would you be interested in having a chat sometime?

Regards

Wes

nova0205, 2024-08-09:
this colaboration gonna be awsome

wnew, 2024-08-12:
@nova0205 unfortunately it doesnt seem that @Yohannfra is supporting this project anymore.

I have some big updates coming for the project I linked above and have started working on a wireless system as well.

Regards

Yohannfra, 2024-08-12:
Hi @wnew,

Thank you for your interest and this collaboration proposition.

You are right, I didn't support this project for years and all I did since the initial release was some small fixes here and there across the project.

The main reason I stopped working on this project is that I was stuck. I couldn't find a solution for the 'common ground' feature. This is the most important feature for such a system but I overlooked it and it doesn't work and won't work with this current implementation with the arduino 'CapacitiveSensor' library, it's too imprecise and not reliable.

I'm mainly a software engineer and don't have enough knowledge in electrical engineering to find how to solve it.

I'd be really interested in a collaboration and willing to get back to this project if we can find how to solve this first.

Last year I also started a V2 based around a NRF52 dongle to improve the fabrication cost and complexity. I now have this V2 that is much much simpler and smaller but I can't release anything if the common ground is not solved first.

V1 client box compared to v2:
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

Let me know if you want to collaborate so we can discuss how it can be done.

Regards

Yohann

wnew, 2024-08-12:
Thank you very much for your reply @Yohannfra

You are right, there are 2 major hurdles to the wireless scoring apparatus. The main one being the lack of a common ground, which could be solved in a couple of ways, but most of these are really complex to implement with the required precision.  The second one is the synchronisation of the 2 "client" devices to within a millisecond. This is vital as wireless communications can be flaky and often require a resend of the packet, so we cant rely on time of arrival at the server side.

I see 3 possible solutions to the common ground problem. 1. Capacitive touch sensing, this takes time to detect and also requires calibration. 2. Time domain reflectometry, highly complex and costly to implement at the nano second scale. 3. Some type of RF signalling and detection as used in radio transceivers. (My initial research leads me to believe this would be a good solution)

I have also played with the idea of designing a modified tip, which would allow for the detection of a touch on a conductive surface. This on its own would only be a partial solution.

I am an electrical engineer so am happy to tackle these challenges.

Anyway, I would like to arrange a zoom call at some stage, with a couple of other similar project developers. How could I get hold of you to arrange this? Otherwise, you can find my email address in the readme here: https://github.com/wnew/fencing_scoring_box

Regards

Wes

wnew, 2024-08-12:
I love your upgraded solution with the NRF, it is a great little device. The external antenna version is also amazing. I have gotten about a km line-of-sight in ideal conditions.

It might also be worth while looking at using the ESP32.

nova0205, 2024-08-12:
@wnew  i just sended a email to you

Yohannfra, 2024-08-12:
> It might also be worth while looking at using the ESP32.

Well I don't think esp32 are a good idea, the power consumption of these is too high for a battery powered device like this. I did a first version with it and esp-now (you can find it in the Archive/ directory).

I will send you an email so we can arrange this zoom call.

nova0205, 2024-08-12:
I'm interested in being part of that Zoom call if you'll allow me.

Plinsboorg, 2024-10-04:
Hi @Yohannfra and @wnew
I'm new to fencing and might not know everything well.
But why can't we apply a certain voltage to the epee guard and the floor?
Say we have 3V3 supplied to the switch on the epee, but the areas that shouldn't be detected are connected to 5V for example.
When you hit the target you will see 3V3. When you hit something you're not supposed to you will see 5V
There can be analog comparator circuit to react to voltage fast and not rely on slow ADC.
Is there some obvious thing that I'm missing here?

METhOphetamine, 2024-10-19:
Hi, I would like to collaborate on this as part of a school project. I think a possible solution for the common ground would be sending PWM signal and detecting it with a tune decoder as is described here: https://forum.arduino.cc/t/wireless-fencing-scoring-system-detecting-a-pwm-signal-without-common-ground/686963

The OP of the thread got stuck because the PWM was also coupling to the inner epee wires. Because of that his solution canceled hits where the blade touched the opponent's guard, not just hits directly on the guard. I would like to try to find a frequency range where the coupling is not that bad. The LM567 tone decoder has voltage values which will be detected and values which will not. So I want to try to find out at which frequency is the coupling attenuation good enough for the LM567's spec.

@Yohannfra, it looks like in the v2 version you are using the Nordic NRF52 dongle. Are you still using platformio then? I know it's not officially supported but there are some workarounds on the internet. Would you be willing to share the unfinished V2?

Could you also please explain the capacitive sensor to me? I know the original library is charging and discharging a capacitor and measuring the time it takes to charge it to find out whether an object is connected to it. But how does that work for sensing hits on the guard? I'm guessing the metal guard takes different time to charge than the fencing jacket?

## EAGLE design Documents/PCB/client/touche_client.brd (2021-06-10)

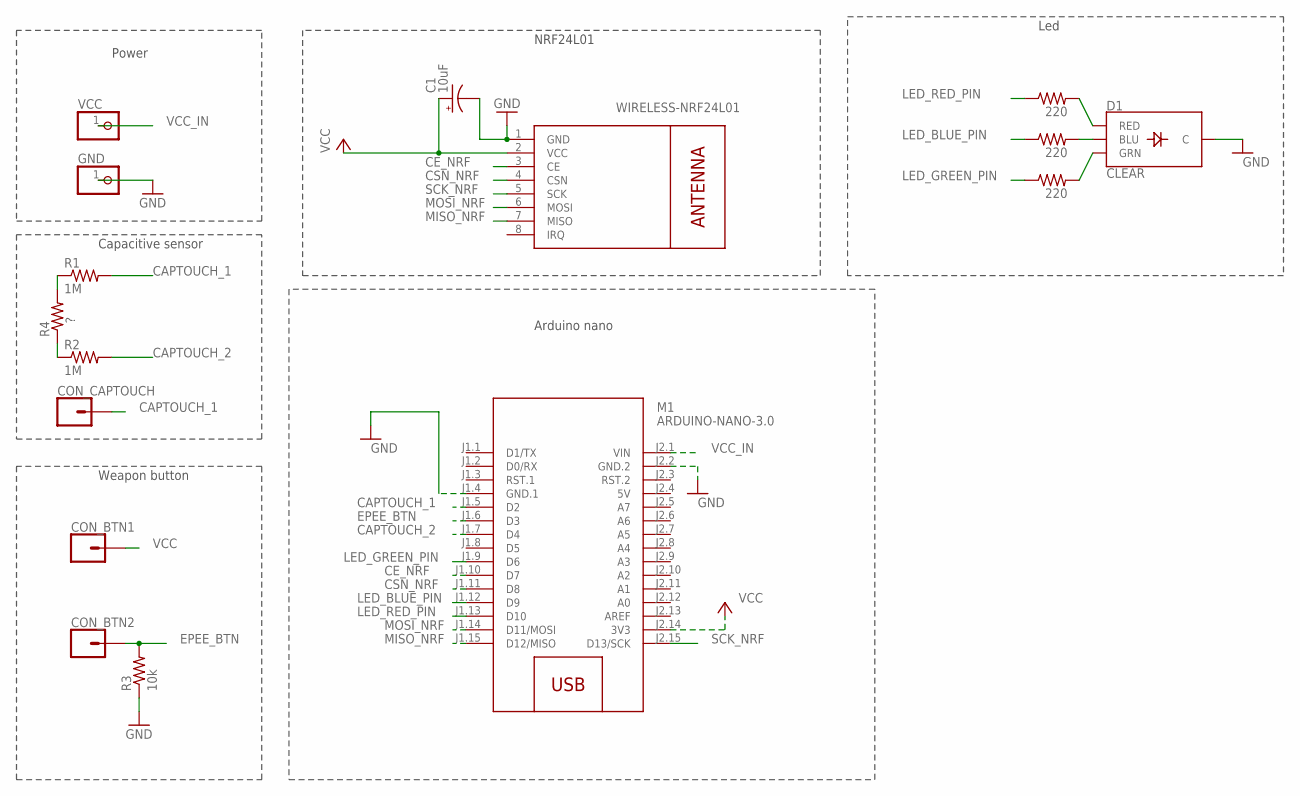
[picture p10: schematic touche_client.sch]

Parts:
C1: 10uF; E2-5
CON_BTN1, CON_BTN2: CONN_01; 1X01
CON_CAPTOUCH: CONN_01; 1X01
D1: CLEAR; LED-RGB-THRU
GND: PINHD-1X1; 1X01
M1: ARDUINO-NANO-3.0
M2: WIRELESS-NRF24L01
R1, R2: 1M; 0204/7
R3: 10k; 0204/7
R4: ?; 0204/7
R_LED1, R_LED2, R_LED3: 220; 0204/7
VCC: PINHD-1X1; 1X01

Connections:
5V: M1.J2.4 (5V)
CAPTOUCH_1: CON_CAPTOUCH.1, M1.J1.5 (D2), R1.2
CAPTOUCH_2: M1.J1.7 (D4), R2.2
CE_NRF: M1.J1.10 (D7), M2.3 (CE)
CSN_NRF: M1.J1.11 (D8), M2.4 (CSN)
EPEE_BTN: CON_BTN2.1, M1.J1.6 (D3), R3.2
GND: C1.-, D1.2 (C), GND.1, M1.J1.4 (GND.1), M1.J2.2 (GND.2), M2.1 (GND), R3.1
LED_BLUE_PIN: M1.J1.12 (D9), R_LED2.1
LED_GREEN_PIN: M1.J1.9 (D6), R_LED3.1
LED_RED_PIN: M1.J1.13 (D10), R_LED1.1
MISO_NRF: M1.J1.15 (D12/MISO), M2.7 (MISO)
MOSI_NRF: M1.J1.14 (D11/MOSI), M2.6 (MOSI)
unnamed: R1.1, R4.2
unnamed: D1.1 (RED), R_LED1.2
unnamed: R2.1, R4.1
unnamed: D1.4 (BLU), R_LED2.2
unnamed: D1.3 (GRN), R_LED3.2
SCK_NRF: M1.J2.15 (D13/SCK), M2.5 (SCK)
VCC: C1.+, CON_BTN1.1, M1.J2.14 (3V3), M2.2 (VCC)
VCC_IN: M1.J2.1 (VIN), VCC.1

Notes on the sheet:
Arduino nano
NRF24L01
Power
Capacitive sensor
Weapon button
Led

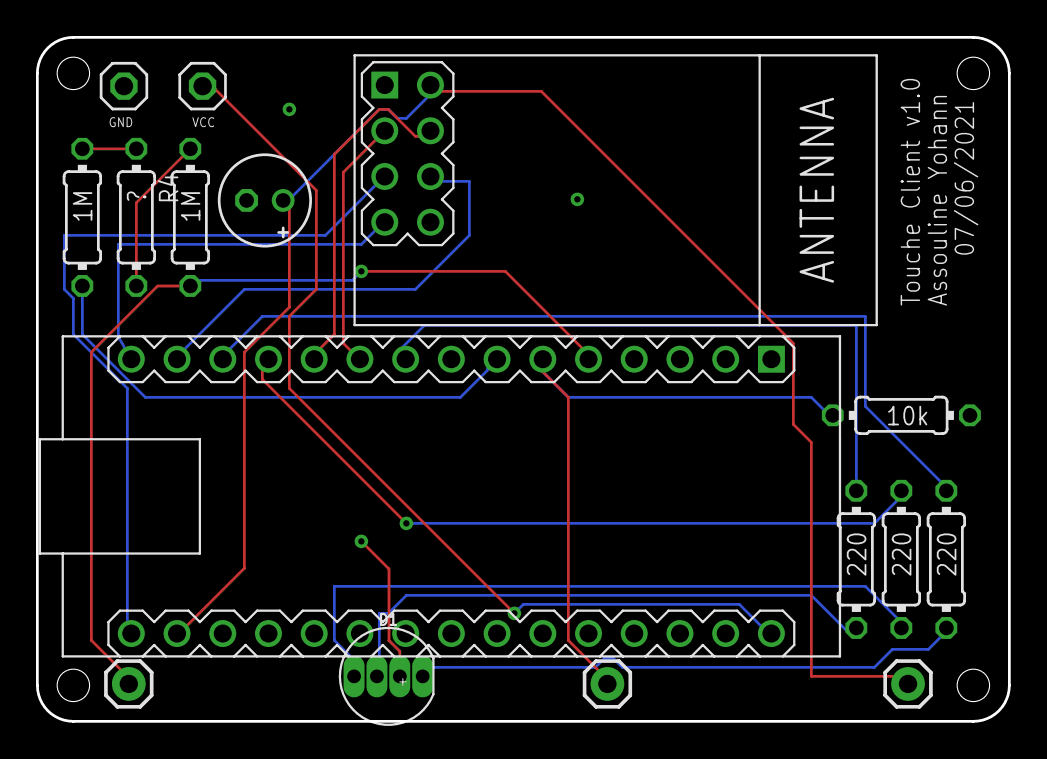
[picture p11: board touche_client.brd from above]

Board: 2 copper layers, 54.0 x 38.0 mm, 16 parts (0 on the bottom side), 19 nets.

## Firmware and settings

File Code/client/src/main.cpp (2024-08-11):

/*
Touché Project
Copyright (C) 2024 Assouline Yohann

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
You should have received a copy of the GNU General Public License
along with this program.  If not, see <http://www.gnu.org/licenses/>.
*/

#include "ArduinoLog.h"
#include "PlayerConfig.hpp"
#include "RGBLed.hpp"
#include "RadioModule.hpp"
#include "Timer.hpp"
#include "VirtualGround.hpp"
#include "Weapon.hpp"
#include "config.h"
#include "protocol.h"
#include "touche.h"
#include "utils.hpp"

#include <Arduino.h>

// Global classes
VirtualGround virtualGround(VIRTUAL_PIN_OUT, VIRTUAL_PIN_IN);
RadioModule radio_module(NRF24L01_CE_PIN, NRF24L01_CS_PIN);
Weapon weapon(EPEE_BUTTON_PIN, virtualGround);
static RGBLed led(LED_PIN_RED, LED_PIN_GREEN, LED_PIN_BLUE);
static Timer timerValidHit;
static Timer timerInvalidHit;
static Timer timerButtonMaintened;
PlayerConfig config(PLAYER_ROLE, DEFAULT_WEAPON_MODE);

void run_calibration_process();

/**
 * @brief callback needed for arduino-log
 */
static void printLineEnding(Print *_logOutput)
{
    _logOutput->print(CRLF);
}

void setup()
{
#ifndef DISABLE_LOGGING
    Serial.flush();
    Serial.begin(9600);

    // view available log level here : https://github.com/Yohannfra/Arduino-Log
    Log.begin(LOG_LEVEL_VERBOSE, &Serial, true);
    Log.setSuffix(printLineEnding);
#endif

    Log.trace(CRLF "==== Booting client ====" CRLF);

    Log.notice("Role: %s", config.getRole() == PLAYER_1 ? "PLAYER_1" : "PLAYER_2");
    Log.notice("Weapon: %s", config.getWeapon() == EPEE ? "EPEE" : "FOIL");

    radio_module.init(config.getRole());

    led.blink(RGBLed::WEAPON_MODE_TO_COLOR(config.getWeapon()), 1000, 1);
}

static void applyAckSettings(ack_payload_t ack)
{
    if (ack == ACK_ERROR) {
        Log.warning("ack is ACK_ERROR");
        return;
    }

    utils::print_ack_payload(ack);

    config.setPisteMode(ack & ACK_PISTE_MODE);

    if (ack & ACK_EPEE && config.getWeapon() != EPEE) {
        config.setWeapon(EPEE);
        virtualGround.reset();
    } else if (ack & ACK_FOIL && config.getWeapon() != FOIL) {
        config.setWeapon(FOIL);
        virtualGround.reset();
    } else if (ack & ACK_SABRE) {
        // config.setWeapon(SABRE);
    }

    Log.notice("Weapon is now : %s", config.getWeapon() == FOIL ? "FOIL" : "EPEE");
    Log.notice("Piste is now : %s", config.getPisteMode() ? "Enabled" : "Disabled");
}

void loop()
{
    Weapon::hit_status_e hit_status = weapon.isHitting(config.getWeapon());

    if (hit_status != Weapon::NONE) {
        if (!timerButtonMaintened.isRunning()) {
            timerButtonMaintened.start();
        }

        if (hit_status == Weapon::VALID && !timerValidHit.isRunning()) {
            Log.notice("== Valid hit ==");
            timerValidHit.start();
            led.setColor(RGBLed::GREEN);
            applyAckSettings(radio_module.sendMsg(HIT));
            timerInvalidHit.reset();
        } else if (!timerInvalidHit.isRunning() && !timerValidHit.isRunning()) {  // INVALID HIT
            Log.notice("== Invalid hit ==");
            if (config.getWeapon() == FOIL) {
                applyAckSettings(radio_module.sendMsg(INVALID_HIT));
            }
            timerInvalidHit.start();
            led.setColor(RGBLed::RED);
        }

        if (timerButtonMaintened.isRunning() &&
            timerButtonMaintened.getTimeElapsed() > 2000 /* 2 secs */) {  // calibration
            run_calibration_process();
            timerButtonMaintened.reset();
        }
    } else {  // No hit occuring
        timerButtonMaintened.reset();

        if (timerValidHit.getTimeElapsed() > FENCING_BLINKING_TIME ||
            timerInvalidHit.getTimeElapsed() > FENCING_BLINKING_TIME) {  // reset all
            Log.notice("Reset");
            led.turnOff();
            timerValidHit.reset();
            timerInvalidHit.reset();
        }
    }
}

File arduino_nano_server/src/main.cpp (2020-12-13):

#include "Buzzer.hpp"
#include "LedRing.hpp"
#include "RadioModule.hpp"
#include "PlayerManager.hpp"
#include "ActionManager.hpp"
#include <Arduino.h>

#include "protocol.h"
#include "fencingConstants.h"
#include "DebugLog.hpp"
#include "utils.hpp"

#define BUZZER_PIN 10
#define LED_RING_PIN 3

Buzzer buzzer(BUZZER_PIN);
LedRing led_ring(LED_RING_PIN);
RadioModule radio_module;
PlayerManager player_manager;
ActionManager action_manager;

void setup()
{
#ifdef DEBUG
    Serial.begin(9600);

    while (!Serial) {
        ; // wait for serial
    }
    utils::print_board_infos();
#endif
    radio_module.init();
    led_ring.init();
}

void resetValues()
{
    DEBUG_LOG_LN("resetting values");
    action_manager.reset();
    led_ring.turn_off();
    buzzer.stop();
}

void loop()
{
    packet_t packet = radio_module.receiveMsg();

    if (packet) {

        DEBUG_LOG_VAL("Received: ", packet);

        device_id_t player_id = GET_ID(packet);
        player_index_e player_index = player_manager.getPlayerFromID(player_id);
        payload_type_e payload = (payload_type_e)((uint8_t)packet);

        DEBUG_LOG_VAL("id: ", player_id);
        DEBUG_LOG_VAL("index: ", player_index);

        if (player_index == NOT_A_PLAYER) {
            player_index_e index = player_manager.registerPlayer(player_id);
            if (index != NOT_A_PLAYER) { // to prevent more than to clients
                led_ring.blink(COLOR_CODE[index], 200);
            }
            return; // no hit on register
        }

        switch (payload)
        {
        case HIT:
            DEBUG_LOG_LN("HIT");
            action_manager.hit(player_index);
            break;
        case CALIBRATION_STARTING:
            DEBUG_LOG_LN("CALIBRATION STARTED");
            led_ring.do_circle_annimation(ORANGE_RGB);
            break;
        case CALIBRATION_END:
            DEBUG_LOG_LN("CALIBRATION END");
            led_ring.blink(GREEN_RGB, 100, 5);
            break;
        case CALIBRATION_FAILED:
            DEBUG_LOG_LN("CALIBRATION FAILED");
            led_ring.blink(RED_RGB, 100, 5);
            break;
        default:
            break;
        }
    }

    hit_type_e hit_type = action_manager.getHitStatus();

    if (hit_type != NO_HIT) {
        buzzer.play();
        if (hit_type == DOUBLE_HIT) {
            led_ring.set_half_colors(RED_RGB, GREEN_RGB);
        } else if (hit_type == HIT_PLAYER_1) {
            led_ring.set_color(RED_RGB);
        } else if (hit_type == HIT_PLAYER_2) {
            led_ring.set_color(GREEN_RGB);
        }
    }
    if (action_manager.isResetTime()) {
        resetValues();
    }
}

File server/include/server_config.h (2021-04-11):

#ifndef SERVER_PINOUT_H
#define SERVER_PINOUT_H

/**
 * @brief Arduino pin used for the buzzer
 */
#define BUZZER_PIN 10

/**
 * @brief Arduino pin used for the piste mode button
 */

#define PIN_BUTTON_PISTE_MODE 4

#define PIN_BUTTON_CHANGE_WEAPON 5

#define PIN_BUTTON_SWITCH_PLAYERS 6

/**
 * @brief Arduino pin used for the neopixel ring
 */
#define LED_RING_PIN 3

/**
 * @brief Arduino pin for chip enable pin of NRF24L01
 */
#define NRF24L01_CE_PIN 7

/**
 * @brief Arduino pin for chip select pin of NRF24L01
 */
#define NRF24L01_CS_PIN 8

#endif /* SERVER_PINOUT_H */

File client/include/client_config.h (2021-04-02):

#ifndef CLIENT_CONFIG_H
#define CLIENT_CONFIG_H

#ifdef WRITE_ROLE_TO_EEPROM
#define ROLE_TO_WRITE PLAYER_1 // change value to PLAYER_1 or PLAYER_2
#endif

/**
 * @brief How long the button must be pressed (and maintened) to start calibration
 */
#define TIME_TO_ACTIVATE_CALIBRATION 2000 // 2 seconds

/**
 * @brief Arduino pin used for the led
 */
#define LED_PIN_RED 10
#define LED_PIN_GREEN 6
#define LED_PIN_BLUE 9

/**
 * @brief Arduino pin for the button of the weapon
 */
#define EPEE_BUTTON_PIN 3

/**
 * @brief Arduino pin for chip enable pin of NRF24L01
 */
#define NRF24L01_CE_PIN 7

/**
 * @brief Arduino pin for chip select pin of NRF24L01
 */
#define NRF24L01_CS_PIN 8

/**
 * @brief Arduino pin for capacitive sensor in
 */
#define VIRTUAL_PIN_IN 2

/**
 * @brief Arduino pin for capacitive sensor out
 */
#define VIRTUAL_PIN_OUT 4

#endif // CLIENT_CONFIG_H

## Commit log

2019-09-24 Create a class to handle the led matrix
2020-03-23 add doc and a sketch to print mac address
2020-03-25 works with leds
2020-03-25 add code for the buzzer
    [main.cpp]
2020-04-07 change digitalRead to analogRead to avoid the trigger when touching the pins
    [main.cpp]
2020-04-07 change url for micro usb charger to an url for micro usb full circuit charge
2020-04-10 add code for led ring
2020-04-24 start working on the ground
2020-07-12 update server code for ground
2020-07-20 update arduino version for easier port
2020-08-01 update and fix esp idf server
    [buzzer.c, server.h]
2020-08-03 fix neopixels for server
    [neopixel.c, neopixel.h]
2020-08-07 update server, ground touch now works
2020-08-10 add get_state function to buzzer
    [buzzer.c]
2020-08-10 update server for ground to work even if hit msg arrived first
2020-08-27 update client with pcb pins
2020-09-04 fix compilation with new version of esp idf
    [neopixel.c]
2020-09-16 update client arduino nano code
2020-09-17 update arduino client
2020-09-17 add arduino server code
2020-09-21 fix ledring code for arduino client
    [main.cpp]
2020-11-30 fix client id stuff
    [main.cpp]
2020-11-30 update ledring
2020-12-07 update led and button to use registers directly
2020-12-07 add function to print board infos
2020-12-07 fix board id printing
2020-12-09 add timer class
2020-12-09 fix potential bug in timer
2020-12-09 fix main and bugs with timers
    [main.cpp]
2020-12-10 update all and fix bugs
    [wssf_client.fzz, wssf_server.fzz]
2020-12-12 update button to use INPUT_PULLUP
2020-12-13 remove ground stuff from server
2020-12-13 update fritzing schemas
    [wssf_client.fzz, wssf_server.fzz]
2020-12-14 update server fritzing
    [wssf_server.fzz]
2020-12-14 rename folder old to archive and arduino nano code becomes main client and server
2020-12-15 add pcb files
    [wssf_arduino_nano_client.brd, wssf_arduino_nano_client.sch, wssf_arduino_nano_server.brd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]
2020-12-22 update pcbs and add gerbers files
    [wssf_arduino_nano_client.brd, wssf_arduino_nano_server.brd, wssf_arduino_nano_server.sch]
2020-12-28 update doc in shared board_id
2021-01-28 fix board id problem using eeprom
    [main.cpp]
2021-01-31 moved board id directory
2021-03-10 add second led ring support
2021-03-10 fix registration blink for two rings mode
    [main.cpp]
2021-03-15 Big update, change radio protocol and use 2 pipes, fix a few bugs here and there, remove id and use role instead
    [client_config.h, main.cpp]
2021-03-22 add cad folder with client stl files
    [base_client.stl, lid_client.stl]
2021-03-22 update cad README
2021-03-22 rename Pcb to PCB and update README
    [wssf_arduino_nano_client.brd, wssf_arduino_nano_client.sch, wssf_arduino_nano_server.brd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]
2021-03-22 rename Pcb to PCB and update README 2
    [wssf_arduino_nano_client.brd, wssf_arduino_nano_client.sch, wssf_arduino_nano_server.brd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]
2021-03-22 rename Fritzing directory, add README and update client design
    [wssf_client.fzz, wssf_server.fzz]
2021-03-22 add bom and empty instructable
2021-03-30 change timer lib to shared and update client makefile
2021-04-02 replace client basic led with rgb led
    [client_config.h]
2021-04-04 add server button class
2021-04-04 update ledRing class
2021-04-13 fix client release compilation
    [main.cpp]
2021-04-13 reorganise directory structure, delete useless fritzing schematics and update README
    [wssf_client.fzz, wssf_server.fzz]
2021-04-15 add pcb sources and gerbers
    [wssf_arduino_nano_client.brd, wssf_arduino_nano_client.sch, wssf_arduino_nano_server.brd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]
2021-04-25 update PCBS and add screenshots
    [wssf_client.brd, wssf_client.sch, wssf_server.brd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]
2021-04-25 update PCBS's readmes
2021-04-25 update CAD files and cad's README
    [base_client.stl, base_server.stl, lid_client.stl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]
2021-04-26 add clang format and fix bidirectional communication using ack instead
    [main.cpp]
2021-05-03 rename weapon_button to weapon, add arduino-log library and fix a few bugs
    [main.cpp]
2021-05-03 start assembly guide
2021-05-03 add pcb ordering to diy guide
2021-05-04 update assembly guide
2021-05-09 replace DEBUG_LOG wit Log from ArduinoLog library
    [main.cpp]
2021-05-13 update arduino-log version
2021-05-13 fix custom ack, it now works and fix a few bugs
    [main.cpp]
2021-05-19 apply weapon changes and buttons changes to server
2021-05-20 update playerConfig to avoid globals variables
    [main.cpp]
2021-05-20 create calibration.cpp for server
2021-05-31 fix calibration animation
2021-05-31 fix client calibration process
2021-06-05 add virtualGround reset function when changing weapon
    [main.cpp]
2021-06-05 update led pins
2021-06-06 add assembly pictures
2021-06-07 update buzzer to use analog based on potentiometer value
    [main.cpp]
2021-06-10 update assembly readme
2021-06-10 update pcb
    [touche_client.brd, touche_client.sch, touche_server.brd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]
2021-06-10 update cad files
    [base_client.stl, base_server.stl, lid_client.stl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]
2021-06-11 add on/off indications on cad to show state
    [lid_client.stl, lid_server.stl]
2021-06-12 set the number of samble for calibration to 50
2021-06-12 read register directly for button
2021-06-12 fix bug with virtual ground reseted at every hit
    [main.cpp]
2021-06-12 fix switch side action
2021-06-18 fix foil button check
2021-06-18 remove useless delay in led blink
2021-06-18 remove useless delay in ledring::blink
2024-08-11 Replace all 2021 with 2024 in licences
    [config.h, main.cpp]

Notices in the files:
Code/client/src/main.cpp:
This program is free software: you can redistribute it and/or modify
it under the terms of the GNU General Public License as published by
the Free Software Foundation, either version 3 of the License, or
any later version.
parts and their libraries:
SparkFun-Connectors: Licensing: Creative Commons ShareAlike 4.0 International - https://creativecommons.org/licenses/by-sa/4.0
